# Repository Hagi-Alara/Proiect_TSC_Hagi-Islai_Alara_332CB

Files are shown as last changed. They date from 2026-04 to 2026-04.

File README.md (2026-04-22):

# InkTime - Open Source Smartwatch

Prezentul repository include documentația tehnică și fișierele de proiectare hardware (stadiul EVT - Engineering Verification Test) pentru proiectul InkTime. Acesta reprezintă un smartwatch open-source, având la bază microcontrolerul nRF52840. Proiectul acoperă întregul ciclu de dezvoltare hardware: specificații, schemă electrică, proiectare PCB și integrare mecanică.

## Descrierea Funcționalității Hardware

Sistemul este arhitecturat în jurul SoC-ului nRF52840, selectat pentru suportul Bluetooth Low Energy (BLE) și eficiența energetică ridicată.

**Module și Interfețe Integrate:**
* **Display E-Paper:** Interfațat prin protocolul SPI, garantând un consum energetic minim (curent absorbit exclusiv în timpul actualizării ecranului).
* **Unitate de Măsură Inerțială (IMU):** Utilizată pentru detectarea gesturilor. Comunicarea se realizează exclusiv prin magistrala I2C.
* **Feedback Haptic:** Motor de vibrații controlat printr-un circuit integrat (driver) dedicat, implementat pentru notificări.
* **Interfață Utilizator:** Trei butoane fizice cu acționare tactilă, configurate cu rezistențe de pull-up interne.
* **Managementul Energiei:** Sistemul este alimentat printr-un acumulator Li-Po conectat direct la pad-urile circuitului imprimat, eliminând conectorul JST pentru a respecta limitările de gabarit pe axa Z. Încărcarea se realizează prin intermediul interfeței USB-C, gestionată de un circuit integrat de management al puterii (PMIC), în timp ce nivelul de încărcare este monitorizat de un Fuel Gauge.

## Bill of Materials (BOM) Principal

| Componentă | Pachet / Capsulă | Funcție |
| :--- | :--- | :--- |
| **nRF52840-QIAA** | aQFN-73 | Microcontroler principal (SoC) + BLE |
| **BMA421** | LGA-12 | IMU (Accelerometru pentru gesturi) |
| **BQ25180** | DSBGA | PMIC (Management Încărcare Baterie) |
| **MAX17048** | TDFN-8 | Fuel Gauge (Monitorizare nivel baterie) |
| **DRV2605** | BGA-9 | Driver Haptic pentru motorul de vibrații |
| **RT6160A** | WLCSP | Regulator DC/DC (Buck-Boost pentru 3.3V) |
| **Conector Molex** | FPC 24-pin 0.5mm | Conector pentru Display E-Paper |

## Maparea Pinilor (nRF52840)

Alocarea pinilor a fost optimizată pentru a minimiza încrucișările de trasee pe cablajul imprimat.

| Pin nRF52840 | Nume Rețea | Interfață / Funcție |
| :--- | :--- | :--- |
| **P$AD10, P$K2, P$AD12** | `EPD_DC`, `EPD_CS`, `EPD_RST` | Control E-Paper (Data/Command, Chip Select, Reset) |
| **P$P13, P$A12** | `MOSI`, `SCK` | SPI Date & Clock pentru afișaj |
| **P$AD12** | `EPD_BUSY` | Status E-Paper (Indicator de ocupare) |
| **P$L1, P$M2** | `SDA`, `SCL` | I2C Date & Clock (PMIC, Fuel Gauge, IMU) |
| **P$AD8, P$AC9, P$W24** | `P0.13`, `P0.14`, `P1.02` | Butoane interfață utilizator (Up, Enter, Down) |
| **P$AD6, P$AD4, P$AD2**| `D+`, `D-`, `VBUS` | USB-C ESD Protection & VBUS Detect |
| **P$U1** | `HAPTIC_EN` | Semnal de activare Driver Haptic |
| **P$T2** | `PMIC_INT` | Întrerupere Baterie Li-Po |
| **P$N1, P$P2** | `IMU_INT1`, `IMU_INT2` | Întreruperi IMU |
| **P$J24** | `ALERT` | Alertă Fuel Gauge |
| **P$AD22, P$AA24, P$AC24** | `SWO`, `SWDCLK`, `SWDIO`| Interfață de depanare (SWD) |
| **P$AC13** | `RESET` | Semnal Hardware Reset |
| **P$Y23** | `P1.01` | Control E-Paper Drive Circuit |

## Randări 3D




## Etape de Implementare

1. **Definirea Specificațiilor și a Componentelor:** Selectarea componentelor necesare respectând cerința unui consum redus de energie (ultra-low-power).
2. **Proiectarea Schemei Electrice (Validare ERC):** Interconectarea subsistemelor de alimentare (PMIC, LDO), logică digitală (I2C, SPI) și radiofrecvență (RF).
3. **Proiectarea Cablajului Imprimat (Validare DRC):** * Amplasarea componentelor respectând constrângerile mecanice ale carcasei.
   * Rutarea traseelor de impedanță controlată pentru antena BLE, cu implementarea zonelor de restricție (Keepout) pe toate straturile.
   * Generarea planurilor de masă (Polygon Pours) pe straturile Top și Bottom.
4. **Validarea Mecanică:** Exportul ansamblului în format 3D STEP pentru verificarea toleranțelor de integrare în carcasa fizică.

## Erori de Proiectare (DRC/ERC) și Decizii de Inginerie Asumate

În urma procesului de verificare automată a regulilor de proiectare și a schemelor electrice (DRC/ERC), au fost raportate o serie de avertismente. Acestea au fost analizate și acceptate intenționat, având la bază următoarele justificări tehnice:

* **Erori ERC: "POWER pin connected to..." (Exemplu: U1 VDD connected to 3V3)**
  * *Justificare:* Aceste avertismente au fost ignorate. Cauza constă în definirea generică a pinilor de alimentare în biblioteca software (ex. "VDD"), în timp ce în schema proiectului rețeaua poartă o denumire specifică ("3V3" sau "VBAT"). Conexiunile sunt corecte din punct de vedere electric.
* **Erori ERC: "Only one pin on net" (Exemplu: SWO, SDA/1.4C, P1.15)**
  * *Justificare:* Aceste erori au fost ignorate. Avertismentele sunt generate deoarece pinii respectivi au fost rutați exclusiv către puncte de test (Test Points) pentru depanare sau au fost etichetați pentru funcționalități viitoare, nefiind conectați la un alt circuit integrat. Prezența lor este necesară pentru testarea hardware.
* **Erori DRC: "Overlap", "Solder mask", "Pad ct Top"**
  * *Justificare:* Aceste erori au fost acceptate. Având în vedere densitatea ridicată a plăcii, toleranțele măștii de lipire (Solder Mask) pentru componentele cu pas foarte mic (cum este conectorul FPC) se suprapun la nivelul software-ului CAD. Aceste deviații se încadrează în capabilitățile și toleranțele standard ale producătorului de cablaje imprimate.
* **Erori DRC: "Board Outline / Copper Clearance"**
  * *Justificare:* Aceste erori au fost acceptate. Erorile sunt provocate de componentele amplasate la limita cablajului (conectorul USB-C, contactele bateriei). Din rațiuni de asamblare mecanică, pinii de susținere și portul trebuie să se intersecteze cu conturul fizic al plăcii (Board Outline). Deși programul raportează o încălcare a regulilor de distanță, implementarea corespunde cerințelor fizice de funcționare.

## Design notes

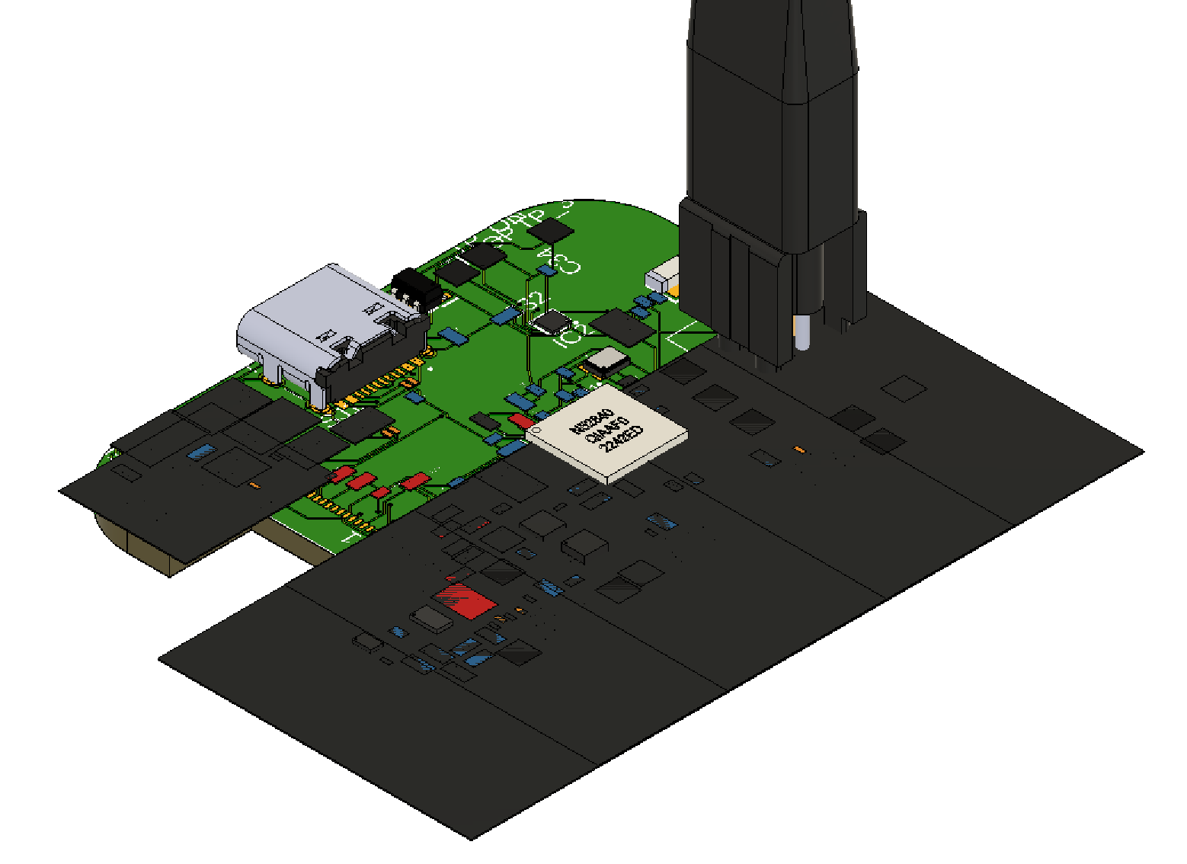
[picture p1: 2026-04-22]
Mechanical/Screenshot 2026-04-22 192517.png

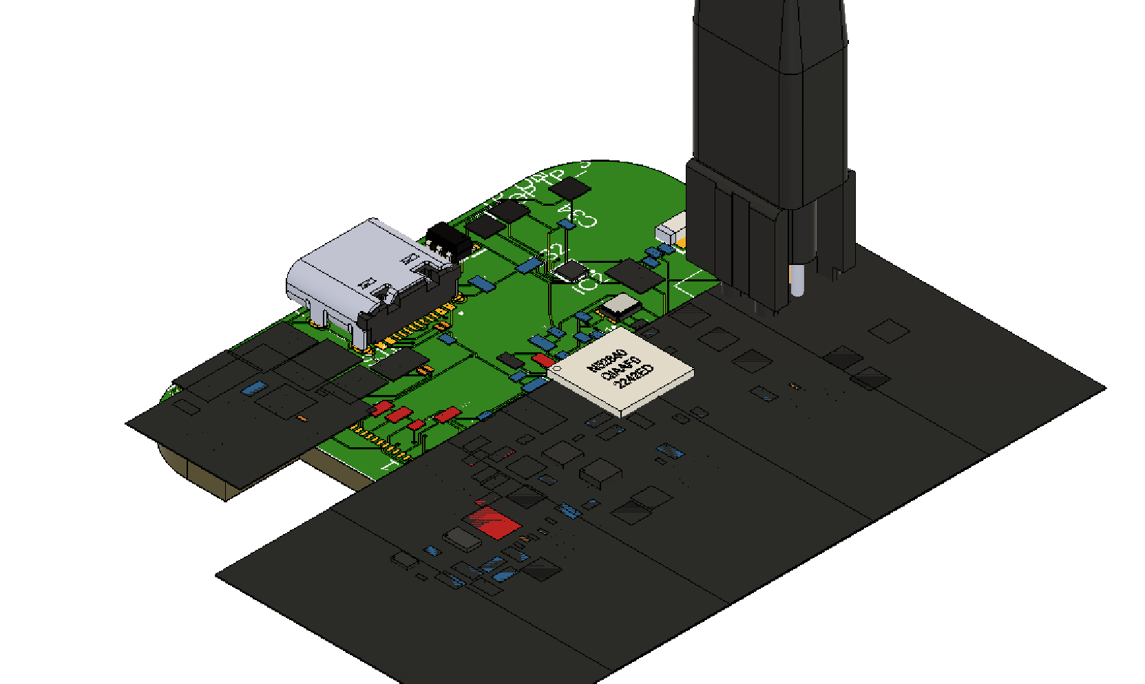
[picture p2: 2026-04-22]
Mechanical/Screenshot 2026-04-22 184206.png

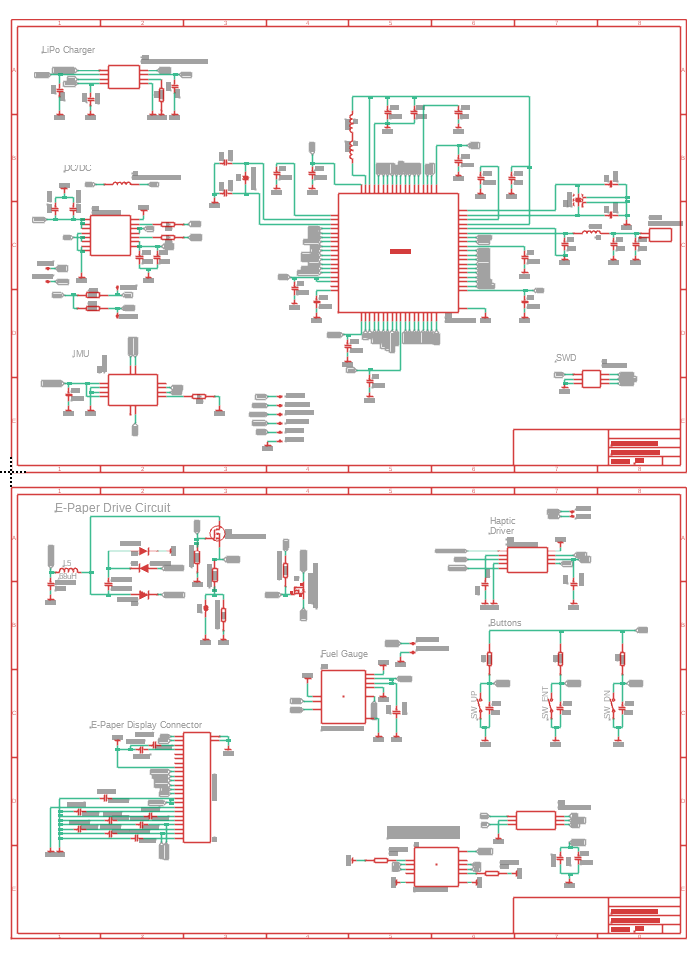
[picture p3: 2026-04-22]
Imagines/Screenshot 2026-04-22 193226.png

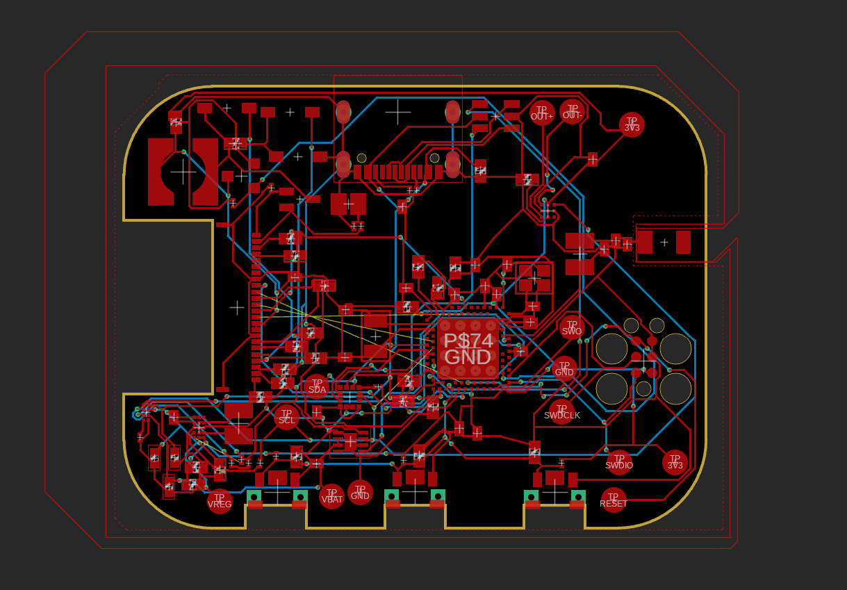
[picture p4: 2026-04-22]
Imagines/Screenshot 2026-04-22 193134.png

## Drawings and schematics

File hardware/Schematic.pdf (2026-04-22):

# DC/DC

# LiPo Charger

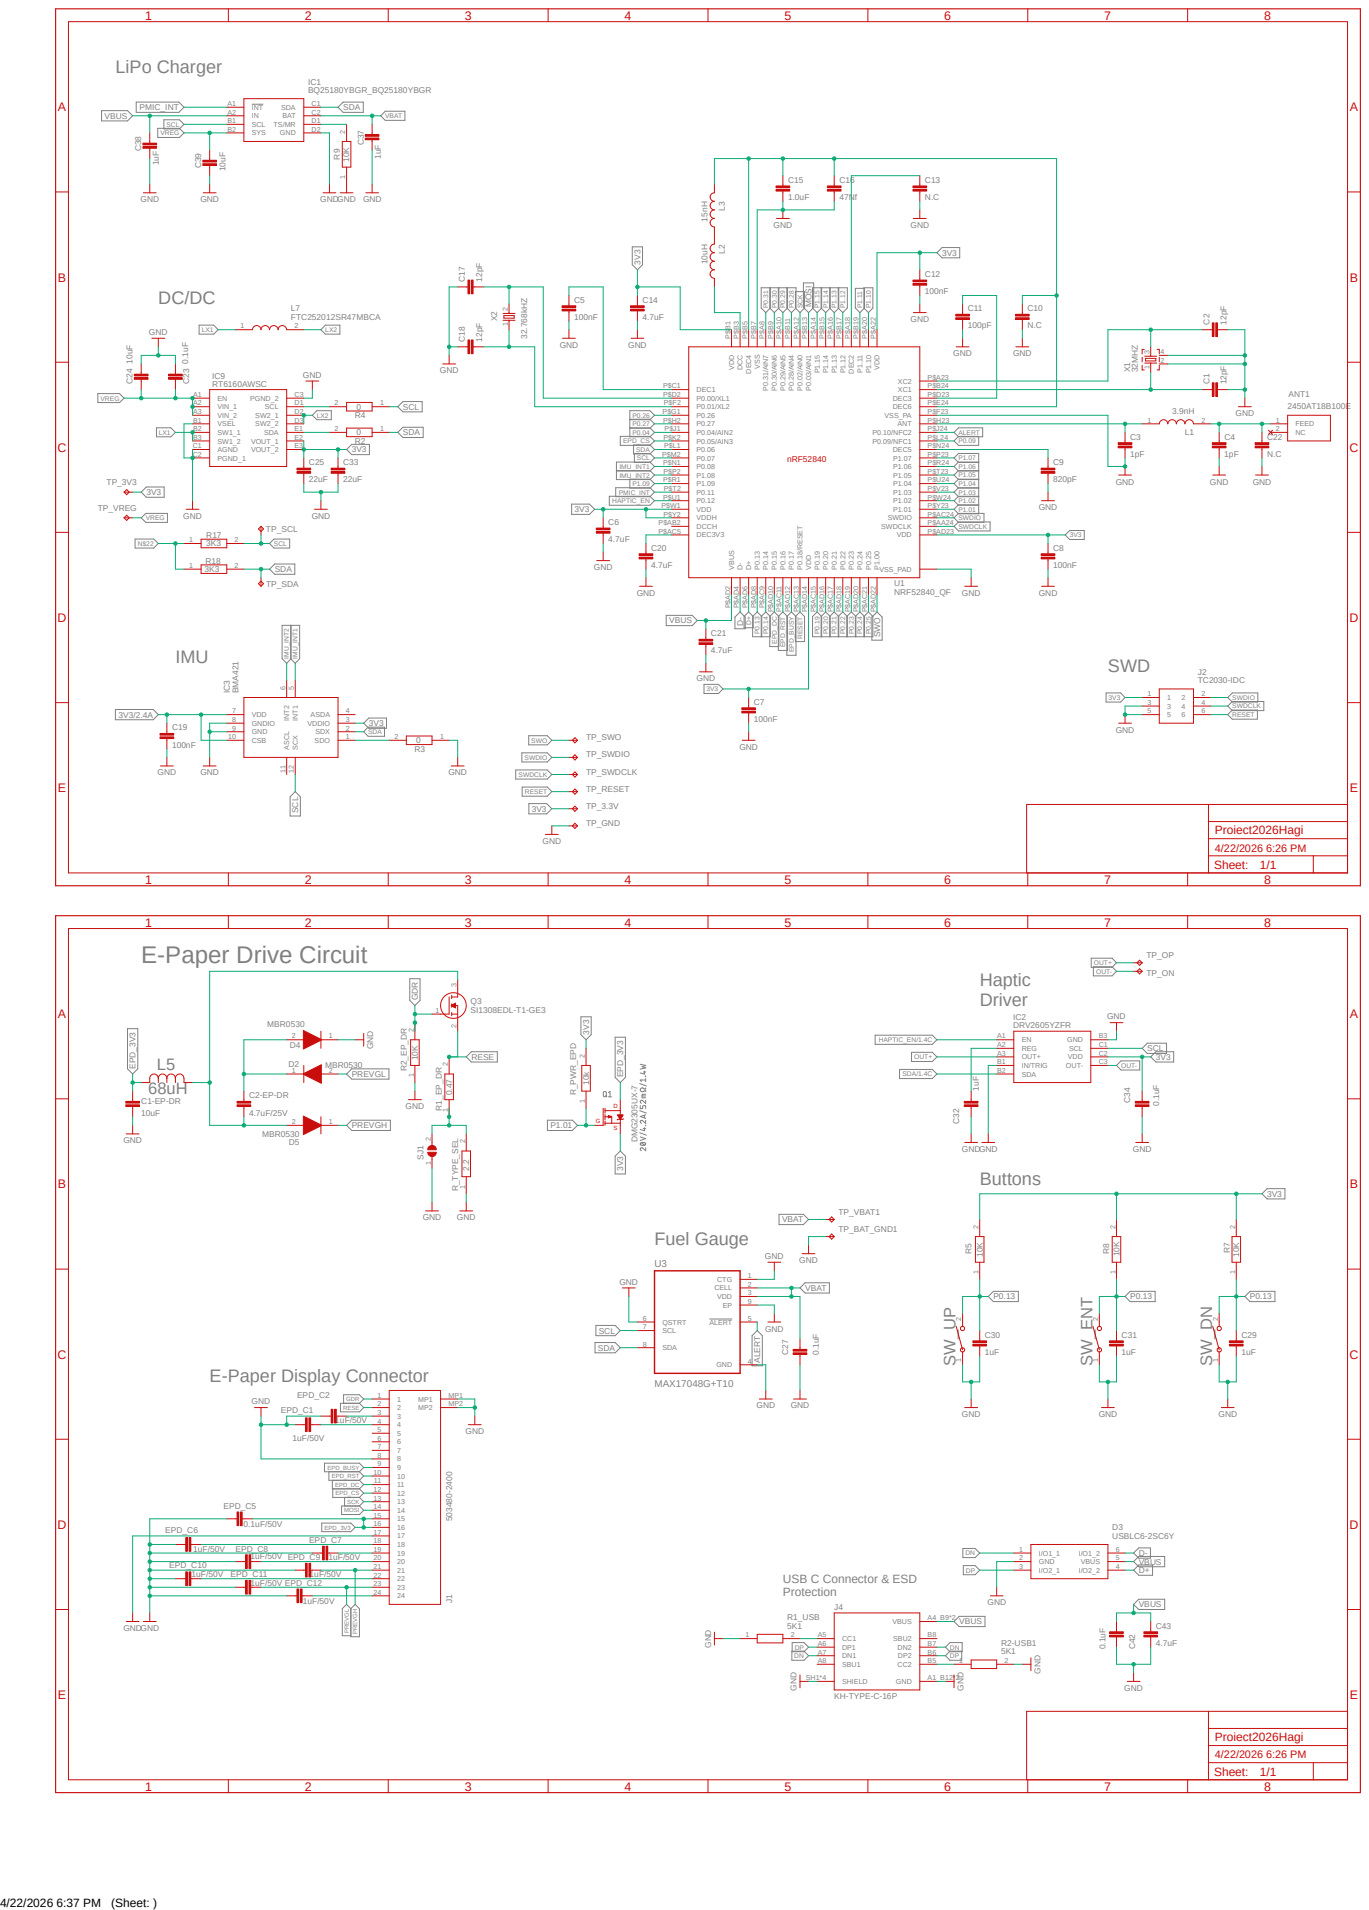
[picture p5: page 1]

RESET RESET P⁰.31 P⁰.30 P⁰.29 P⁰.28 SCK

1uF/50V EPD_C11 | 1uF/50V | | 22 22

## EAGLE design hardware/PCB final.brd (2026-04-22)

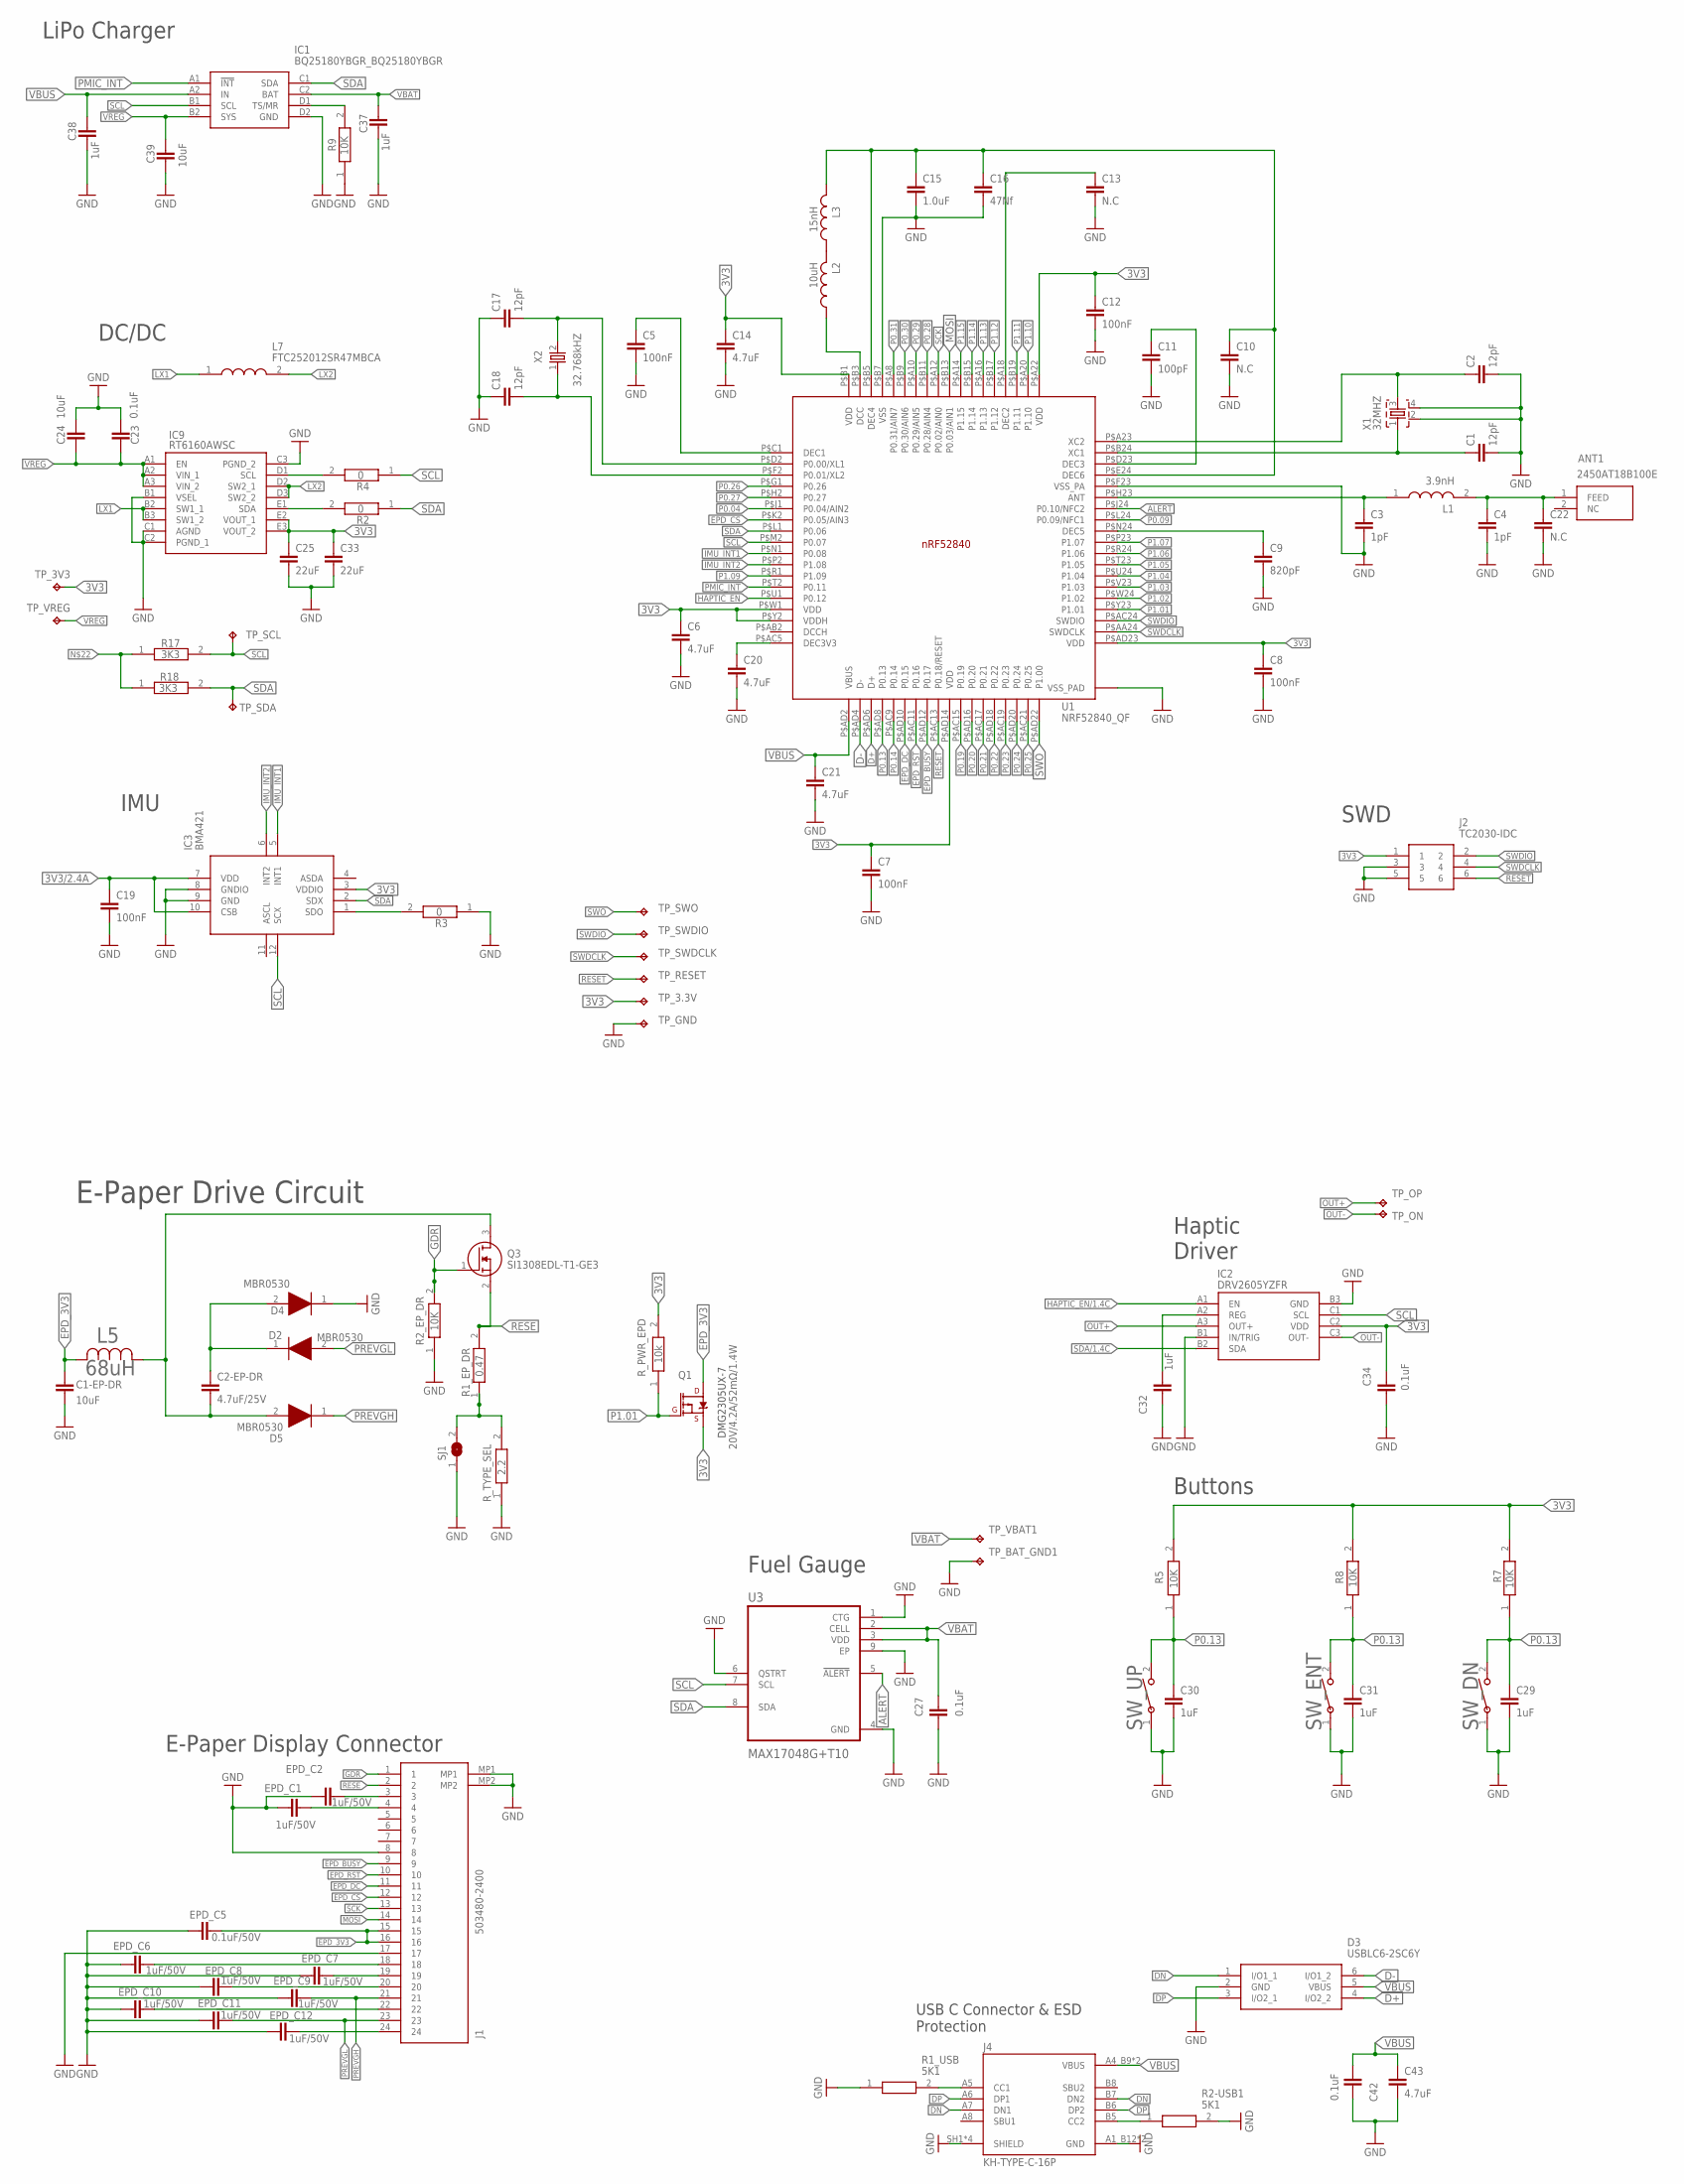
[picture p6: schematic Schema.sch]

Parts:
ANT1: 2450AT18B100E; 2450AT18B100E_ANTC3216X140N
C1, C2, C17, C18: 12pF; NORDIC_NRF_3_RESC0201_L
C1-EP-DR: 10uF; NORDIC_NRF_3_RESC0402_L
C2-EP-DR: 4.7uF/25V; NORDIC_NRF_3_RESC0402_L
C3, C4: 1pF; NORDIC_NRF_3_RESC0201_L
C5, C7, C8, C12, C19: 100nF; NORDIC_NRF_3_RESC0201_L
C6, C14, C20, C21, C43: 4.7uF; NORDIC_NRF_3_RESC0402_L
C9: 820pF; NORDIC_NRF_3_RESC0201_L
C10, C13, C22: N.C; NORDIC_NRF_3_RESC0201_L
C11: 100pF; NORDIC_NRF_3_RESC0201_L
C15: 1.0uF; NORDIC_NRF_3_RESC0402_L
C16: 47Nf; NORDIC_NRF_3_RESC0201_L
C23: 0.1uF; NORDIC_NRF_3_RESC0402_L
C24: 10uF; NORDIC_NRF_3_RESC0201_L
C25, C33: 22uF; NORDIC_NRF_3_RESC0402_L
C27, C34, C42: 0.1uF; NORDIC_NRF_3_RESC0201_L
C29, C30, C31, C32: 1uF; NORDIC_NRF_3_RESC0402_L
C37, C38: 1uF; PERFECT_0402_0402
C39: 10uF; PERFECT_0402_0402
D2, D4, D5: MBR0530; ESP32_C6_LIBRARY_5_SOD3716X135N
D3: USBLC6-2SC6Y; ESP32_C6_LIBRARY_3_SOT95P280X145-6N
EPD_C1, EPD_C2, EPD_C6, EPD_C7, EPD_C8, EPD_C9, EPD_C10, EPD_C11, EPD_C12: 1uF/50V; NORDIC_NRF_3_RESC0402_L
EPD_C5: 0.1uF/50V; NORDIC_NRF_3_RESC0201_L
IC1: BQ25180YBGR_BQ25180YBGR; BQ25180YBGR_BGA8C40P2X4_100X155X50
IC2: DRV2605YZFR; DRV2605YZFR_BGA9C50P3X3_144X144X62
IC3: BMA421; BMA423_BMA423
IC9: RT6160AWSC; RT6160AWSC_BGA15C40P3X5_140X230X60
J1: 503480-2400; 503480-2400_5034802400
J2: TC2030-IDC; TC2030-IDC_TC2030IDC
J4: KH-TYPE-C-16P; KH-TYPE-C-16P_KINGHELM_KH-TYPE-C-16P
L1: 3.9nH; MLP2016SR47MT0S1_INDC2016X100N
L2: 10uH; NORDIC_NRF_2_RESC0402_L
L3: 15nH; NORDIC_NRF_2_RESC0402_L
L5: 68uH; ESP32_C6_LIBRARY_2_IND_4828-WE-TPC_WRE
L7: FTC252012SR47MBCA; MLP2016SR47MT0S1_INDC2016X100N
Q1: 20V/4.2A/52mΩ/1.4W; ESP32_C6_LIBRARY_4_ESP32_C6_LIBRARY_4_ESP32_C6_LIBRARY_4_ES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
Q3: SI1308EDL-T1-GE3; ESP32_C6_LIBRARY_6_SOT65P210X110-3N
R1_EP_DR: 0.47; CPF0201D7K68C1_0201
R1_USB, R2-USB1: 5K1; CPF0201D7K68C1_0201
R2, R3, R4: 0; CPF0201D7K68C1_0201
R2_EP_DR, R5, R7, R8, R9: 10K; CPF0201D7K68C1_0201
R17, R18: 3K3; CPF0201D7K68C1_0201
R_PWR_EPD: 10k; CPF0201D7K68C1_0201
R_TYPE_SEL: 2.2; CPF0201D7K68C1_0201
SJ1: ESP32_C6_LIBRARY_7_JUMPER_SJ
SW_DN: 2025-10-22_07-23-44_LIBRARY_EVP-AKE31ASW_EVP-AKE3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; 2025-10-22_07-23-44_LIBRARY_SW_EVP-AKE31A_PAN
SW_ENT: 2025-10-22_07-23-44_LIBRARY_EVP-AKE31ASW_EVP-AKE3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; 2025-10-22_07-23-44_LIBRARY_SW_EVP-AKE31A_PAN
SW_UP: 2025-10-22_07-23-44_LIBRARY_EVP-AKE31ASW_EVP-AKE3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; 2025-10-22_07-23-44_LIBRARY_SW_EVP-AKE31A_PAN
TP_3.3V, TP_3V3: HECTOR_WATCH_1_TPTP20R; HECTOR_WATCH_1_TP20R
TP_BAT_GND1: HECTOR_WATCH_1_TPTP20R; HECTOR_WATCH_1_TP20R
TP_GND: HECTOR_WATCH_1_TPTP20R; HECTOR_WATCH_1_TP20R
TP_ON: HECTOR_WATCH_1_TPTP20R; HECTOR_WATCH_1_TP20R
TP_OP: HECTOR_WATCH_1_TPTP20R; HECTOR_WATCH_1_TP20R
TP_RESET: HECTOR_WATCH_1_TPTP20R; HECTOR_WATCH_1_TP20R
TP_SCL: HECTOR_WATCH_1_TPTP20R; HECTOR_WATCH_1_TP20R
TP_SDA: HECTOR_WATCH_1_TPTP20R; HECTOR_WATCH_1_TP20R
TP_SWDCLK: HECTOR_WATCH_1_TPTP20R; HECTOR_WATCH_1_TP20R
TP_SWDIO: HECTOR_WATCH_1_TPTP20R; HECTOR_WATCH_1_TP20R
TP_SWO: HECTOR_WATCH_1_TPTP20R; HECTOR_WATCH_1_TP20R
TP_VBAT1: HECTOR_WATCH_1_TPTP20R; HECTOR_WATCH_1_TP20R
TP_VREG: HECTOR_WATCH_1_TPTP20R; HECTOR_WATCH_1_TP20R
U1: NRF52840_QF; NORDIC_NRF_4_AQFN50P700X700X85_HS-74N
U3: MAX17048G+T10; ESP32_C6_LIBRARY_SON50P200X200X80-9N
X1: 32MHZ; NORDIC_NRF_BT-XTAL_2016_N
X2: 32.768kHZ; NORDIC_NRF_1_XTAL_3215_N

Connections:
3V3: C6.1, C7.1, C8.1, C12.1, C14.1, C25.1, C33.1, C34.1, IC2.C2 (VDD), IC3.3 (VDDIO), IC9.E2 (VOUT_1), IC9.E3 (VOUT_2), J2.1, Q1.2 (S), R5.2, R7.2, R8.2, R_PWR_EPD.2, TP_3.3V.TP, TP_3V3.TP, U1.P$A22 (VDD), U1.P$AD14 (VDD), U1.P$AD23 (VDD), U1.P$B1 (VDD), U1.P$W1 (VDD), U1.P$Y2 (VDDH)
3V3/2.4A: C19.1, IC3.7 (VDD), IC3.10 (CSB)
ALERT: U1.P$J24 (P0.10/NFC2), U3.5 (!ALERT)
D+: D3.4 (I/O2_2), U1.P$AD6 (D+)
D-: D3.6 (I/O1_2), U1.P$AD4 (D-)
DN: D3.1 (I/O1_1), J4.A7 (DN1), J4.B7 (DN2)
DP: D3.3 (I/O2_1), J4.A6 (DP1), J4.B6 (DP2)
EPD_3V3: C1-EP-DR.1, EPD_C5.2, J1.15, J1.16, L5.2, Q1.3 (D)
EPD_BUSY: J1.9, U1.P$AD12 (P0.17)
EPD_CS: J1.12, U1.P$K2 (P0.05/AIN3)
EPD_DC: J1.11, U1.P$AD10 (P0.15)
EPD_RST: J1.10, U1.P$AC11 (P0.16)
GDR: J1.1, Q3.1 (G), R2_EP_DR.2
GND: C1.2, C1-EP-DR.2, C2.2, C3.2, C4.2, C5.2, C6.2, C7.2, C8.2, C9.2, C10.2, C11.2, C12.2, C13.2, C14.2, C15.2, C16.2, C17.1, C18.1, C19.2, C20.2, C21.2, C22.2, C23.1, C24.1, C25.2, C27.2, C29.2, C30.2, C31.2, C32.2, C33.2, C34.2, C37.2, C38.2, C39.2, C42.2, C43.2, D3.2 (GND), D4.1 (K), EPD_C1.1, EPD_C2.1, EPD_C5.1, EPD_C6.1, EPD_C7.1, EPD_C8.1, EPD_C9.1, EPD_C10.1, EPD_C11.1, EPD_C12.1, IC1.D2 (GND), IC2.B1 (IN/TRIG), IC2.B3 (GND), IC3.8 (GNDIO), IC3.9 (GND), IC9.B1 (VSEL), IC9.C1 (AGND), IC9.C2 (PGND_1), IC9.C3 (PGND_2), J1.8, J1.17, J1.MP1, J1.MP2, J2.3, J2.5, J4.A1_B12 (GND), J4.A12_B1 (GND), J4.SH1 (SHIELD), J4.SH2 (SHIELD), J4.SH3 (SHIELD), J4.SH4 (SHIELD), R1_USB.1, R2-USB1.2, R2_EP_DR.1, R3.1, R9.1, R_TYPE_SEL.1, SJ1.1, SW_DN.1, SW_ENT.1, SW_UP.1, TP_BAT_GND1.TP, TP_GND.TP, U1.P$74 (VSS_PAD), U1.P$75 (VSS_PAD), U1.P$76 (VSS_PAD), U1.P$77 (VSS_PAD), U1.P$78 (VSS_PAD), U1.P$79 (VSS_PAD), U1.P$80 (VSS_PAD), U1.P$81 (VSS_PAD), U1.P$82 (VSS_PAD), U1.P$83 (VSS_PAD), U1.P$84 (VSS_PAD), U1.P$85 (VSS_PAD), U1.P$86 (VSS_PAD), U1.P$87 (VSS_PAD), U1.P$88 (VSS_PAD), U1.P$89 (VSS_PAD), U1.P$90 (VSS_PAD), U1.P$B7 (VSS), U1.P$F23 (VSS_PA), U3.1 (CTG), U3.4 (GND), U3.6 (QSTRT), U3.9 (EP), X1.2, X1.4
HAPTIC_EN: U1.P$U1 (P0.12)
HAPTIC_EN/1.4C: IC2.A1 (EN)
IMU_INT1: IC3.5 (INT1), U1.P$N1 (P0.08)
IMU_INT2: IC3.6 (INT2), U1.P$P2 (P1.08)
LX1: IC9.B2 (SW1_1), IC9.B3 (SW1_2), L7.1
LX2: IC9.D2 (SW2_1), IC9.D3 (SW2_2), L7.2
MOSI: J1.14, U1.P$B13 (P0.03/AIN1)
unnamed: IC9.D1 (SCL), R4.2
unnamed: C5.1, U1.P$C1 (DEC1)
unnamed: C9.1, U1.P$N24 (DEC5)
unnamed: C20.1, U1.P$AC5 (DEC3V3)
unnamed: C11.1, U1.P$D23 (DEC3)
unnamed: IC9.E1 (SDA), R2.2
unnamed: IC1.D1 (TS/MR), R9.2
unnamed: J4.A5 (CC1), R1_USB.2
unnamed: IC3.1 (SDO), R3.2
unnamed: L2.1, U1.P$B3 (DCC)
unnamed: C10.1, C15.1, C16.1, L3.2, U1.P$B5 (DEC4), U1.P$E24 (DEC6)
unnamed: C3.1, L1.1, U1.P$H23 (ANT)
unnamed: ANT1.1 (FEED), C4.1, C22.1, L1.2
unnamed: C1.1, U1.P$B24 (XC1), X1.1
unnamed: C2.1, U1.P$A23 (XC2), X1.3
unnamed: C17.2, U1.P$D2 (P0.00/XL1), X2.2
unnamed: C18.2, U1.P$F2 (P0.01/XL2), X2.1
unnamed: L2.2, L3.1
unnamed: R17.1, R18.1
unnamed: C13.1, U1.P$A18 (DEC2)
unnamed: J4.B5 (CC2), R2-USB1.1
unnamed: C32.1, IC2.A2 (REG)
unnamed: EPD_C2.2, J1.3
unnamed: EPD_C1.2, J1.4
unnamed: EPD_C6.2, J1.18
unnamed: EPD_C7.2, J1.19
unnamed: EPD_C8.2, J1.20
unnamed: EPD_C10.2, J1.22
unnamed: EPD_C12.2, J1.24
unnamed: C2-EP-DR.2, D5.2 (A), L5.1, Q3.3 (D)
unnamed: C2-EP-DR.1, D2.1 (K), D4.2 (A)
unnamed: R1_EP_DR.1, R_TYPE_SEL.2, SJ1.2
OUT+: IC2.A3 (OUT+), TP_OP.TP
OUT-: IC2.C3 (OUT-), TP_ON.TP
P0.04: U1.P$J1 (P0.04/AIN2)
P0.09: U1.P$L24 (P0.09/NFC1)
P0.13: C29.1, C30.1, C31.1, R5.1, R7.1, R8.1, SW_DN.2, SW_ENT.2, SW_UP.2, U1.P$AD8 (P0.13)
P0.14: U1.P$AC9 (P0.14)
P0.19: U1.P$AC15 (P0.19)
P0.20: U1.P$AD16 (P0.20)
P0.21: U1.P$AC17 (P0.21)
P0.22: U1.P$AD18 (P0.22)
P0.23: U1.P$AC19 (P0.23)
P0.24: U1.P$AD20 (P0.24)
P0.25: U1.P$AC21 (P0.25)
P0.26: U1.P$G1 (P0.26)
P0.27: U1.P$H2 (P0.27)
P0.28: U1.P$B11 (P0.28/AIN4)
P0.29: U1.P$A10 (P0.29/AIN5)
P0.30: U1.P$B9 (P0.30/AIN6)
P0.31: U1.P$A8 (P0.31/AIN7)
P1.01: Q1.1 (G), R_PWR_EPD.1, U1.P$Y23 (P1.01)
P1.02: U1.P$W24 (P1.02)
P1.03: U1.P$V23 (P1.03)
P1.04: U1.P$U24 (P1.04)
P1.05: U1.P$T23 (P1.05)
P1.06: U1.P$R24 (P1.06)
P1.07: U1.P$P23 (P1.07)
P1.09: U1.P$R1 (P1.09)
P1.10: U1.P$A20 (P1.10)
P1.11: U1.P$B19 (P1.11)
P1.12: U1.P$B17 (P1.12)
P1.13: U1.P$A16 (P1.13)
P1.14: U1.P$B15 (P1.14)
P1.15: U1.P$A14 (P1.15)
PMIC_INT: IC1.A1 (!INT), U1.P$T2 (P0.11)
PREVGH: D5.1 (K), EPD_C9.2, J1.21
PREVGL: D2.2 (A), EPD_C11.2, J1.23
RESE: J1.2, Q3.2 (S), R1_EP_DR.2
RESET: J2.6, TP_RESET.TP, U1.P$AC13 (P0.18/RESET)
SCK: J1.13, U1.P$A12 (P0.02/AIN0)
SCL: IC1.B1 (SCL), IC2.C1 (SCL), IC3.12 (SCX), R4.1, R17.2, TP_SCL.TP, U1.P$M2 (P0.07), U3.7 (SCL)
SDA: IC1.C1 (SDA), IC3.2 (SDX), R2.1, R18.2, TP_SDA.TP, U1.P$L1 (P0.06), U3.8 (SDA)
SDA/1.4C: IC2.B2 (SDA)
SWDCLK: J2.4, TP_SWDCLK.TP, U1.P$AA24 (SWDCLK)
SWDIO: J2.2, TP_SWDIO.TP, U1.P$AC24 (SWDIO)
SWO: TP_SWO.TP, U1.P$AD22 (P1.00)
VBAT: C27.1, C37.1, IC1.C2 (BAT), TP_VBAT1.TP, U3.2 (CELL), U3.3 (VDD)
VBUS: C21.1, C38.1, C42.1, C43.1, D3.5 (VBUS), IC1.A2 (IN), J4.A4_B9 (VBUS), J4.A9_B4 (VBUS), U1.P$AD2 (VBUS)
VREG: C23.2, C24.2, C39.1, IC1.B2 (SYS), IC9.A1 (EN), IC9.A2 (VIN_1), IC9.A3 (VIN_2), TP_VREG.TP

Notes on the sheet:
IMU
DC/DC
LiPo Charger
SWD
USB C Connector & ESD Protection
E-Paper Display Connector
E-Paper Drive Circuit
DMG2305UX-7
Haptic Driver
Buttons
Fuel Gauge

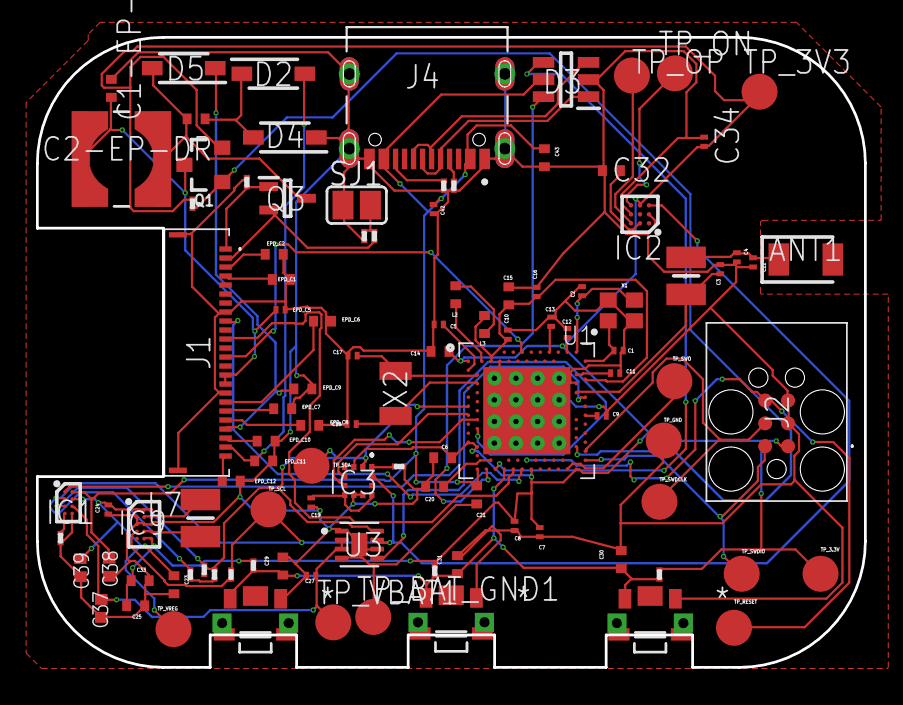
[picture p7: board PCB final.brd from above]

Board: 2 copper layers, 46.0 x 35.0 mm, 105 parts (0 on the bottom side), 69 nets.

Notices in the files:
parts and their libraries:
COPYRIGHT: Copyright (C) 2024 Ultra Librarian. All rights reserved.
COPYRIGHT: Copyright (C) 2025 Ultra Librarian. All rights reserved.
